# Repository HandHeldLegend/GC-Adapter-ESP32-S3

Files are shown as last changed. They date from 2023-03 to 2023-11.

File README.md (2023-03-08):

# GC Pocket Adapter Firmware
This is the official Github page for the GC Pocket Adapter from Hand Held Legend.

## Software and PCB License
<br />This firmware and PCB model are licensed under a <a rel="license" href="http://creativecommons.org/licenses/by-nc-sa/3.0/">Creative Commons Attribution-NonCommercial-ShareAlike 3.0 Unported License</a>.

## 3D Models License

<br />The 3D shell, buttons, and light pipe are licensed under a <a rel="license" href="http://creativecommons.org/licenses/by/4.0/">Creative Commons Attribution 4.0 International License</a>.

## Shop Links
- [GC Pocket Adapter Kit (Includes 3D Printed Parts)](https://handheldlegend.com/products/gc-pocket-adapter-adapter-for-gamecube-controllers)
- [PCB for GC Pocket Adapter (BYO 3D Parts)](https://handheldlegend.com/products/hardware-kit-for-gc-pocket-adapter)
- [Screw, Ball, and Spring Hardware Kit](https://handheldlegend.com/products/hardware-kit-for-gc-pocket-adapter)

## Detailed Information
All of our guides on assembly, updating the firmware, and operation
are listed on [our Wiki page linked here](https://wiki.handheldlegend.com/gc-pocket-adapter).

## 3D Parts
All 3D parts are in the [/3d directory](https://github.com/HandHeldLegend/GC-Adapter-ESP32-S3/tree/main/3d) on this Github repo in STEP format. A 3D STEP file is provided for accurate reference on the PCB dimensions.

For simpler printing with the smaller bits, we have array components for the buttons and light pipe in the [/3d/arrayed parts directory](https://github.com/HandHeldLegend/GC-Adapter-ESP32-S3/tree/main/3d/arrayed%20parts). These are prepared as STL files.

## Assembled Adapter

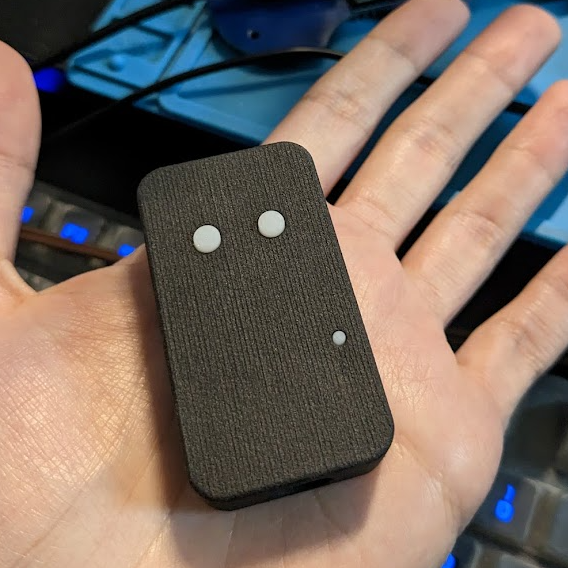
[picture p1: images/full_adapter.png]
Adapter Front

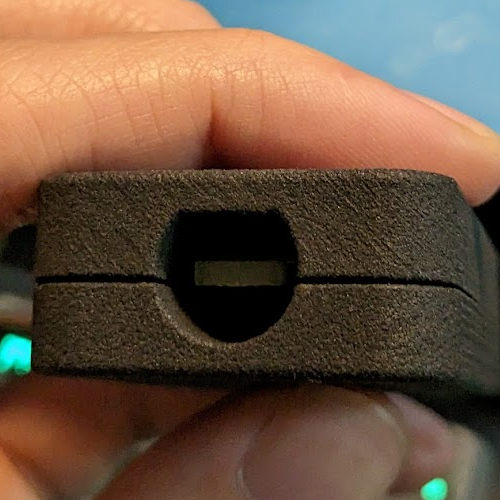
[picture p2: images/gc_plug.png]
Adapter Plug

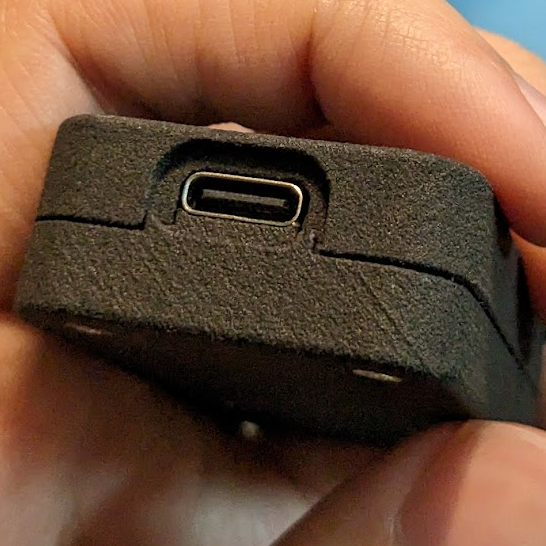
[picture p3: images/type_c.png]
USB Plug


## Features
- 4 USB HID Input modes
- Web configurator to change settings
- Adapts GameCube controllers for use on Windows, Mac, Android, and Nintendo Switch
- Up to 1ms USB polling rate (Dependent on machine it's plugged in to)
- Nintendo Switch only supports 8ms polling rate (Locked by Nintendo Switch)
- Dynamically aligned controller polling (Controller poll auto-aligns to USB poll for optimal response times)
- RGB LED indicator light
- Two buttons to add function to device

## Basic Operation
- When the device is plugged in, the LED light shows a color to indicate which mode it is in. 
	- Blue - DInput/Configuration Mode
	- Yellow - Nintendo Switch Mode
	- Purple - GameCube OEM Mode 
	- Green - XInputHID Mode
- With no controllers connected, pressing the left/right button will switch the current input mode.
- The light will fade to red to indicate it is in standby. Plug in a controller and the light will turn white to indicate the controller is detected.

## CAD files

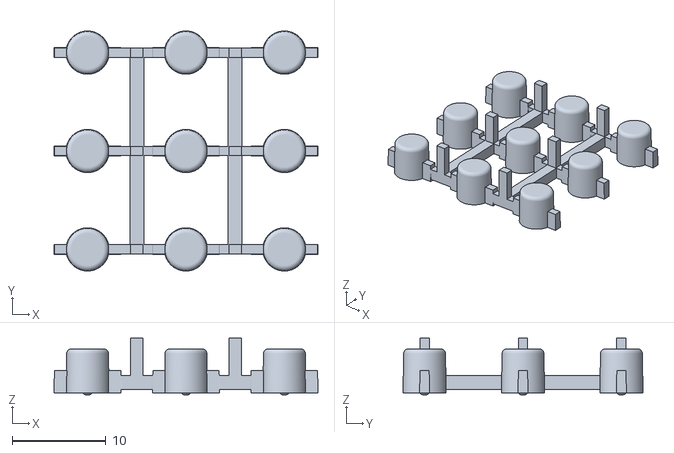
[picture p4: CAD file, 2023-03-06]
3d/arrayed parts/array buttons.stl
28.2 x 25.6 x 6.05

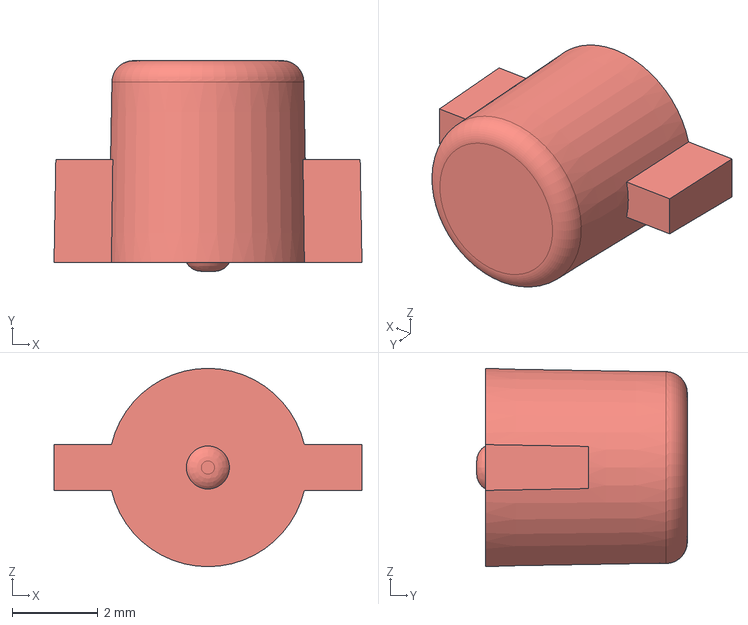
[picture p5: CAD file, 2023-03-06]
3d/Button.step
7.16 x 4.90 x 4.61 mm

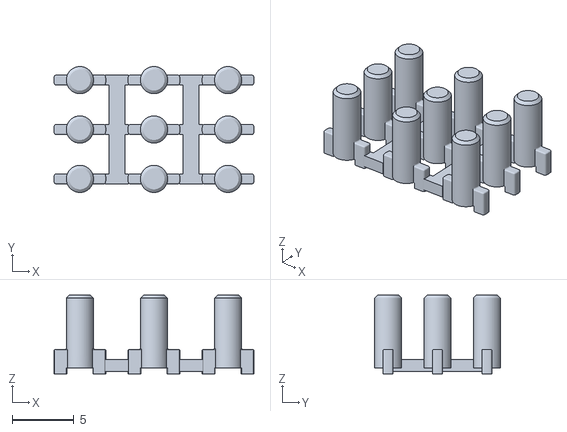
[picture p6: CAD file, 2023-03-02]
3d/arrayed parts/array lightpipes.stl
16.2 x 10.2 x 6.40

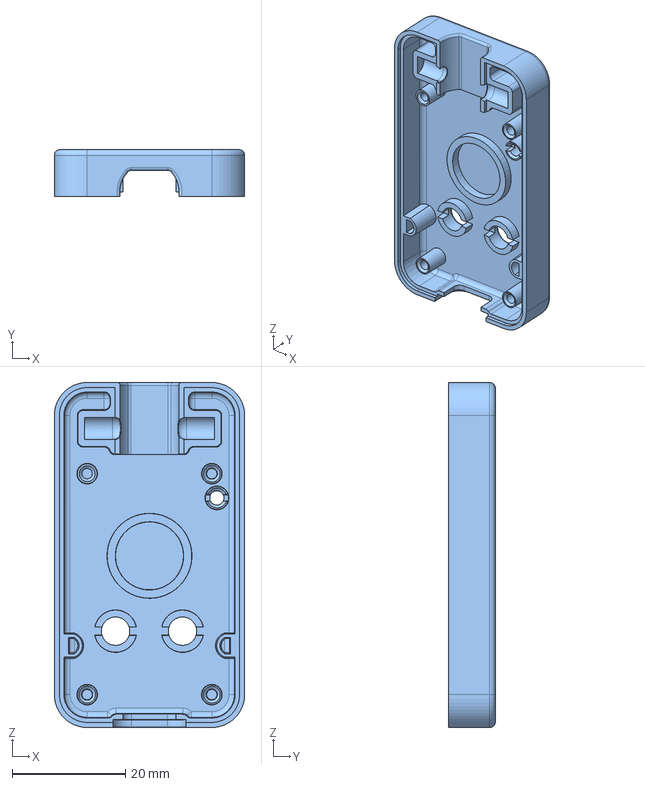
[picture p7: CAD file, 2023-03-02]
3d/Top.step
33.6 x 8.25 x 60.9 mm

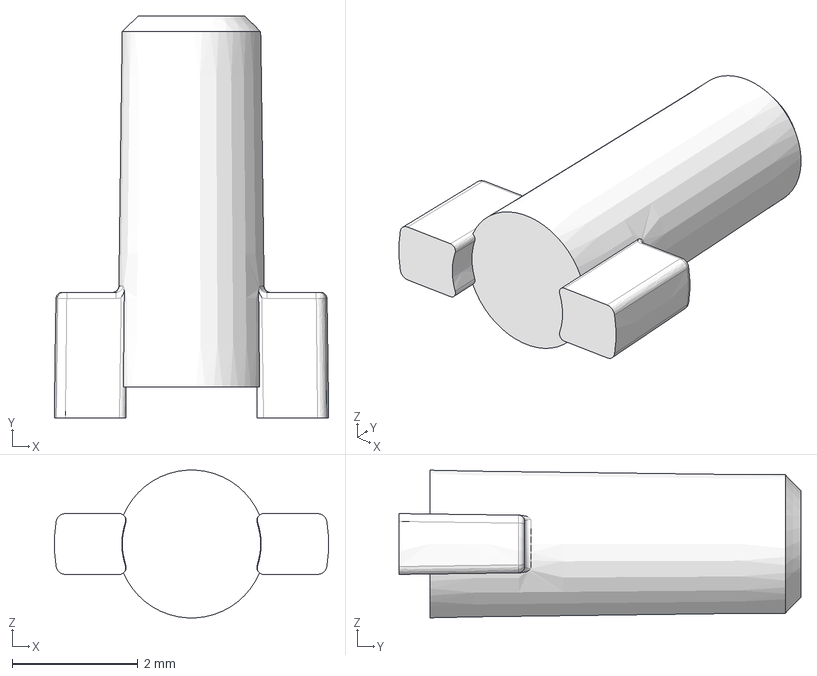
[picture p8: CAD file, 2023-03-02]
3d/LightPipe.step
4.36 x 6.40 x 2.35 mm

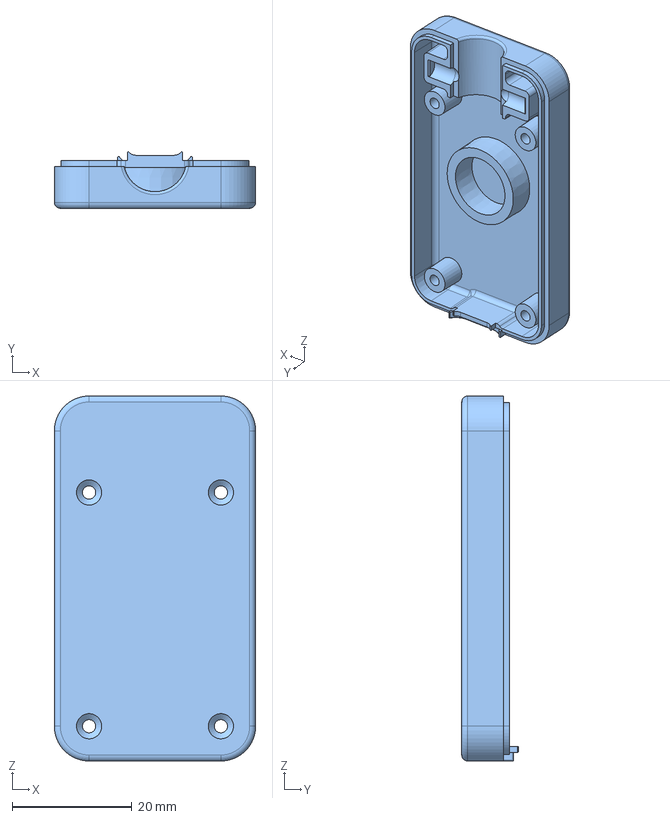
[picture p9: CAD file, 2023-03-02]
3d/Bottom.step
33.6 x 9.44 x 60.9 mm

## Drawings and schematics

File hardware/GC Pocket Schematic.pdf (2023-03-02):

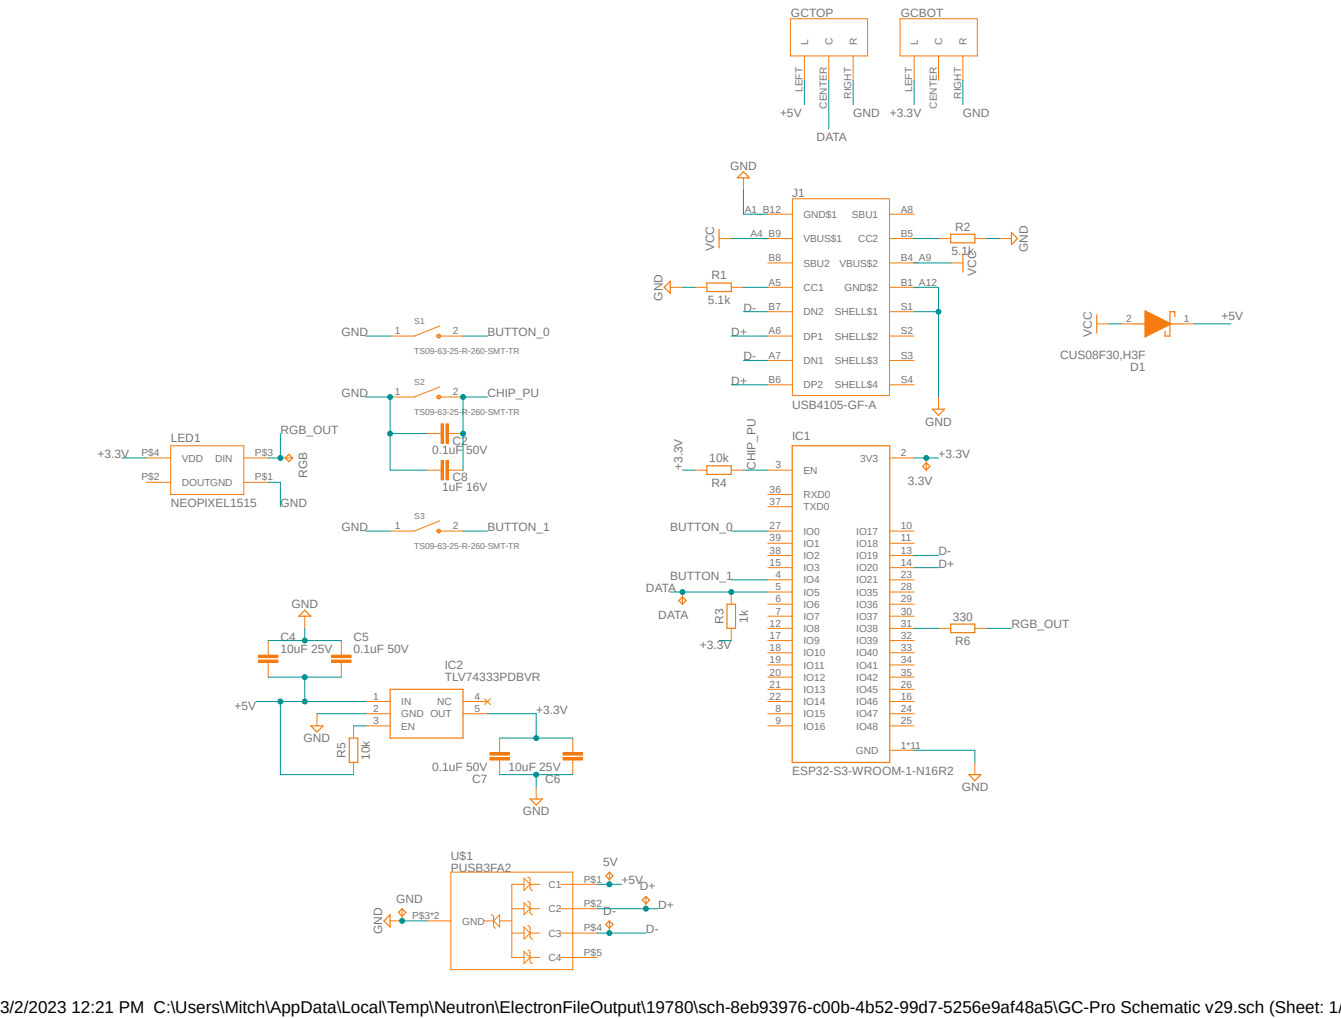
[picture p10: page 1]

3/2/2023 12:21 PM C:\Users\Mitch\AppData\Local\Temp\Neutron\ElectronFileOutput\19780\sch-8eb93976-c00b-4b52-99d7-5256e9af48a5\GC-Pro Schematic v29.sch (Sheet: 1/1)

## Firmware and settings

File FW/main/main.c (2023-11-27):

#include "main.h"

bool cb_adapter_hardware_test()
{
    adapter_ll_hardware_setup();
    rgb_init();

    // Flash all three rgb colors then we can return our test value
    rgb_set_instant(COLOR_RED.color);
    vTaskDelay(1000/portTICK_PERIOD_MS);
    rgb_set_instant(COLOR_GREEN.color);
    vTaskDelay(1000/portTICK_PERIOD_MS);
    rgb_set_instant(COLOR_BLUE.color);
    vTaskDelay(1000/portTICK_PERIOD_MS);
    rgb_set_instant(COLOR_WHITE.color);
    vTaskDelay(1000/portTICK_PERIOD_MS);
    rgb_set_instant(0x00);
    vTaskDelay(1000/portTICK_PERIOD_MS);
    return true;
}

void app_main(void)
{

    /*const gpio_config_t led_latency_pin_config = {
        .pin_bit_mask = LED_PIN_MASK,
        .mode = GPIO_MODE_OUTPUT,
        .intr_type = GPIO_INTR_DISABLE,
        .pull_up_en = false,
        .pull_down_en = false,
    };
    ESP_ERROR_CHECK(gpio_config(&led_latency_pin_config));*/

    
    vTaskDelay(100/portTICK_PERIOD_MS);


    adapter_main_init();

    adapter_main_loop();

}

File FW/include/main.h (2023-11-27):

#ifndef MAIN_H
#define MAIN_H

#include "adapter_includes.h"

// Some definitions for USB Timing
#define TIMEOUT_GC_US 500
#define TIMEOUT_COUNTS 10

#define NON_P_MODE_DELAY 550

#define GC_AXIS_CENTER 128
#define SCALE_AXIS_CENTER 128
#define SIGNED_SCALER (float)

#define LED_BUTTON_PIN (GPIO_NUM_9)
#define LED_USB_PIN (GPIO_NUM_10)

#define LED_PIN_MASK ( (1ULL << LED_BUTTON_PIN) | (1ULL << LED_USB_PIN) )



#endif

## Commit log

2022-11-02 Broke some eggs to get RGB working
    Turns out ESP32 S3 does not support Idle low by default as an SPI master. Ok... so I added some conditional flags to invert this. Also have to invert the bytes going out : )
    Colors now getting out proper.
    [main.c, rmt_gc.h]
2022-12-11 12.11.2022 Update
    Fixes GC native mode
    [main.c]
2022-12-13 12.12.2022 Update
    Resolves issue with scaling relating to some math problems :)
    Thanks to BIGMODENERGY for finding this bug so quickly.
    [main.c]
2022-12-15 Resolve issue with GC adapter mode rumble
    [main.c]
2023-01-12 Added submodule components/esp32-neopixel
2023-01-12 Nicer LED Change and button function
    Added home/capture button function in NS mode.
2023-03-02 Add 3D Files for printing
    [Bottom.step, Button.step, LightPipe.step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]
2023-03-02 Add 3D PCB reference
2023-03-02 Add PDF Schematic
2023-03-06 Update 3d file button
    Change tolerance to 0.2mm
    [Button.step, array buttons.stl]
2023-03-08 Added Z-Jump and many other fixes
    - Dynamic polling alignment
    - Better button function for mode selection (left/right button)
    - separated config commands to ensure new commands can be added later
    [main.c, rmt_gc.h]
2023-03-17 Revert timer change for now
2023-03-18 More USB issue resolution
    [main.c]
2023-03-25 Fix smash box compatibility
    [rmt_gc.h]
2023-04-28 Added 'performance mode' to resolve NS/GC mode issue on Switch.
2023-08-17 Fix change mode animation
    [main.c]
2023-11-12 Removed submodule components/esp32-neopixel
2023-11-27 Update backend
    adds button lockout
2023-11-27 Add esp32 manifest
2023-11-28 Fix manifest esp32
2023-11-28 Fix build manifest for ESP32 flash
2023-11-28 Fix esp32 rumble
2023-11-28 Rumble GC Mode fix
    - Resolve edge case with single port rumble
    [joybus_itf.c]
2024-01-28 1.27.2024 Update
    - Add mode saving by pressing both buttons together
    - More consistent 1khz performance
2024-02-07 2.6.2024 Update
    Fix switch mode scaling
